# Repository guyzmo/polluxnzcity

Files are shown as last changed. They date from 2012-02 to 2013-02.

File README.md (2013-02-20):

Pollux'NZ City Project
======================

The pollux'NZ City project aims at creating a network of autonomous wireless network
of sensors that uploads the measures on any data silos on Internet.

This repository contains the source code of the first prototype of the project, that
has been deployed  in south of France, with the participation of INRIA Sofia Antipolis,
for a first test run.

Description
===========

The projects is made of two modules:
 * the 'autonomous measuring module', that is made of
   * an arduino with a zigbee radio module ;
   * a battery pack that powers the system ;
   * a solar panel that charges the battery ;
   * an i2c network of sensors.
 * the 'gateway module', that is made of
   * a beaglebone with a zigbee radio module

How it works ?
==============

First, after pluging it in, the user configures the gateway module for his sensor 
network and the interval time between two measures. Then he places the autonomous
sensor module to the best sunlight exposure so the autonomous measuring module can
keep the battery filled up.

The gateway will wait for the given interval time, and waken up the measuring module.
It will then order the measuring module to run the fan, so a free air sample is taken
into the box and run in sequence each sensor to get the measured value. Once all the
sensors have been interrogated, it will tell the measuring module to shut itself down.
Finally, all the measures are given to the enabled plugins that will push the data to
every configured data silo.

Project details
===============

Structure of the project
------------------------

 * Directories

<pre>
PolluxNZCity
    |-- PolluxConfig ............. Contains the configuration plugin (in python)
    |   |-- debian ............... Helper files for package generation
    |   |-- pollux ............... Python module
    |-- PolluxGateway ............ Main program that interfaces with the measuring modules
    |   |-- conf ................. Configuration files that are to be deployed in /etc
    |   |-- extensions ........... Python plugins for uploading data to data silos
    |   |-- include .............. Headers
    |   |-- src .................. Sources
    |   `-- tests ................ Tools that helps testing
    |-- PolluxWakeupduino ........ Main firmware code for the arduino in the measuring module
    |-- PolluxSensorBoard ........ Firmware code for the fan, temperature and noise board
    |-- PolluxSensorDust ......... Firmware code for the dust board
    |-- PolluxSensorSensoric ..... Firmware code for the electrochemical sensoric sensors board
    |-- PolluxSensorTemp ......... Firmware code for the external temperature sensor board
    `-- PolluxContribIpks ........ Helper scripts to build binary packages (for angstrom)
</pre>

 * Branches
   * inria_branch: contains the source code deployed for the INRIA test run
   * i2c_refactoring: non-tested base for a full refactoring of the i2c network

 * Other

In PolluxContribIpks, the package.sh script will run a build and generate the packages
– PolluxConfig and PolluxGateway – that are embedded on the beaglebone. That generator
is now deprecated, the recipes for generating those packages working and being accessible
for the angstrom build system.

Description of the main modules
-------------------------------

* _PolluxConfig_: this module is a web application based on the `bottle.py` module that
  exposes RESTful pathes to the web interface that exposes them using `bootstrap.js`.
  The most important parts are in the `pollux_config` module that contains all the exposed
  routes.
* _PolluxGateway_: this module is the main program that parses the configuration, runs 
  the radio, interrogates every sensor on the distant modules and sends the results
  through every datastore module.
* _PolluxWakeUpduino_: this firmware is the code executed by the embedded arduino that
  is only a gateway between XBee and the i2c network.

The _PolluxGateway_ module has documentation embedded you can generate using `doxygen`,
or by running `make doc` in the directory.

Build and Install
-----------------

* _PolluxConfig_

<pre>
 % cd PolluxConfig
 % python bootstrap.py
 % bin/buildout
 % bin/pollux_config_paster
</pre>

* _PolluxGateway_

first you will need to install the arm-gcc for crosscompilation, or run it directly
on a beaglebone, using native gcc.

<pre>
 % make
 % make doc
 % pollux\_gateway -h
</pre>

for a more verbose version of the software, you can run `make verbose`, that will
create a `pollux\_gateway\_verbose` executable.

Caveats
=======

* The I2C model has been mis-designed. 

We have implemented the i2c stack of the whole project following the way the i2c model
has been implemented in the Arduino and ATTiny wire library suggested ; so we followed
a function calling alike protocol.

But we rapidely found out that this kind of implementation is flawed for our use of 
i2c, as it is not flexible enough and not compatible with most of the i2c modules of
the market. So there's a unfinished implementation of the new i2c handling in the
`i2c_refactoring` branch. That has been not tested at all, and not all the sensors'
firmware has been switched to it.

* The _PolluxGateway_ modules deserves better verbosity

First, instead of compiling two different targets, it should have the common `-v`
switch that makes the executable output more messages. But the verbosity shall also
have levels, so the output is not flooded by the messages.

* The _PolluxGateway_ module shall not configure the MUX values for the xbee cape

We have implemented our first versions of the XBee Cape without the helper EEPROM
that helps the cape autoconfigure the MUX values of the beaglebone. With the new
version of the cape, all the code that configures the MUX settings shall be dropped.
This will finally makes the module work only in userland, and not need to start as
root and drop its privileges once the MUX settings are set.

* The _PolluxGateway_ module and _PolluxWakeUpduino_ firmware shall configure all the zigbee settings

We rely on the manual setting of the XBee modules, to match them up and to configure
their pin ports. That operation is cumbersome, does not work all the time, and needs
to use the X-CTU application under windows.

TODO
====

* finish the refactoring of the i2c stacks
* add more verbosity to the _PolluxGateway_ module
* remove the MUX configuration at _PolluxGateway_ start
* add configuration of the XBee radios in the _PolluxGateway_ module and
  _PolluxWakeUpduino_ firmware.

Copyright
=========

(c)2011-2013 Lucas Fernandez and Bernard Pratz, CKAB, hackable:Devices

 * http://polluxnzcity.org/
 * http://ckab.com/polluxnz-city/
 * http://hackable-devices.org/projects/project/polluxnzcity/

All our original work is licensed under the GNU GPL version 3
and all our schematics are under the Creative Commons v3.0 Attribution Share-Alike.

Here are the Libraries we use in our projects, and their respective copyrights notice

Arduino libraries:
 * Statistics by Rob Tillaart and Gil Ross, in the Public Domain 
 * usiTwiSlave, by Donald R. Blake, Jochen Toppe and Ben Galvin under GPL v2
 * circular buffer based on Akash Nath, in the Public Domain
 * Arduino, by the Arduino team, under the GPL v2

For the python web interface:
 * bottle.py under the MIT License
 * bootstrap.js under the Apache License v2.0.
 * deansi library by David Garcia Garzon, under the AGPLv3

All components symbols in the schematics are from Eagle's libraries, under Creative
Commons v3.0 Share-Alike.

License
=======

This program is free software: you can redistribute it and/or modify
it under the terms of the GNU General Public License as published by
the Free Software Foundation, either version 3 of the License, or
(at your option) any later version.

This program is distributed in the hope that it will be useful,
but WITHOUT ANY WARRANTY; without even the implied warranty of
MERCHANTABILITY or FITNESS FOR A PARTICULAR PURPOSE.  See the
GNU General Public License for more details.

You should have received a copy of the GNU General Public License
along with this program.  If not, see <http://www.gnu.org/licenses/>.

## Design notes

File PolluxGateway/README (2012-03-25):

Pollux Gateway Application
==========================

This program runs the network of sensor devices for the Pollux'nz City project.

Dependencies
============

 * libgcrypt    <http://www.gnu.org/s/libgcrypt/>
 * libjson-glib <http://live.gnome.org/JsonGlib>

Compilation
===========

 % make

You can put in environment a "DEFINE" variable having : 
 * VERBOSE
    to have more output
 * API_ESCAPED_MODE
    to change XBee API Mode from 1 to 2 (still untested)

Execution
=========

 % ./pollux_gateway

License
=======

 * GPLv3        <http://www.gnu.org/licenses/gpl.html>

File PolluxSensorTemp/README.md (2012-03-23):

Board for dust detection for final fing pollux.

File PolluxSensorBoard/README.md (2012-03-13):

Sensor board for final fing pollux.

This sensor board include :
* temperature
* SPL
* Dust PM10

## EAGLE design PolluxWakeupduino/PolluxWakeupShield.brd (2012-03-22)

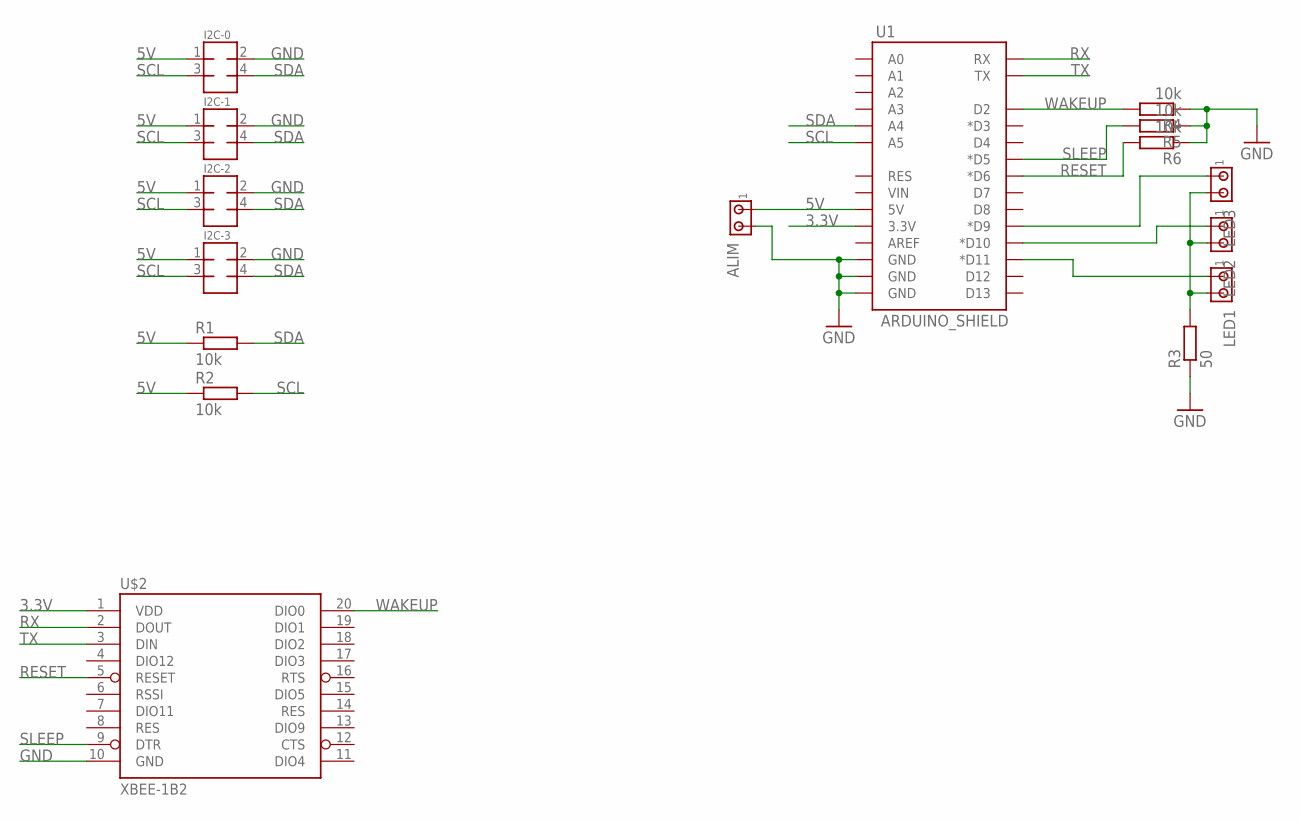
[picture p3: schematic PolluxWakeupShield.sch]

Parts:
ALIM: MTA02-100; 10X02MTA
I2C-0, I2C-1, I2C-2, I2C-3: MMATCH-4-PTH; AMP-215079-4
LED1, LED2, LED3: MTA02-100; 10X02MTA
R1, R2, R4, R5, R6: 10k; 0204/7
R3: 50; 0204/7
U1: ARDUINO_SHIELD; DUEMILANOVE_SHIELD
U$2: XBEE-1B2; XBEE-SILK

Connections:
3.3V: U1.3.3V, U$2.1 (VDD)
5V: ALIM.1, I2C-0.1, I2C-1.1, I2C-2.1, I2C-3.1, R1.1, R2.1, U1.5V
GND: ALIM.2, I2C-0.2, I2C-1.2, I2C-2.2, I2C-3.2, R3.1, R4.1, R5.1, R6.1, U1.GND@0 (GND), U1.GND@1 (GND), U1.GND@2 (GND), U$2.10 (GND)
unnamed: LED1.2, LED2.2, LED3.2, R3.2
unnamed: LED3.1, U1.D9 (*D9)
unnamed: LED2.1, U1.D10 (*D10)
unnamed: LED1.1, U1.D11 (*D11)
RESET: R6.2, U1.D6 (*D6), U$2.5 (RESET)
RX: U1.RX, U$2.2 (DOUT)
SCL: I2C-0.3, I2C-1.3, I2C-2.3, I2C-3.3, R2.2, U1.A5
SDA: I2C-0.4, I2C-1.4, I2C-2.4, I2C-3.4, R1.2, U1.A4
SLEEP: R5.2, U1.D5 (*D5), U$2.9 (DTR)
TX: U1.TX, U$2.3 (DIN)
WAKEUP: R4.2, U1.D2, U$2.20 (DIO0)

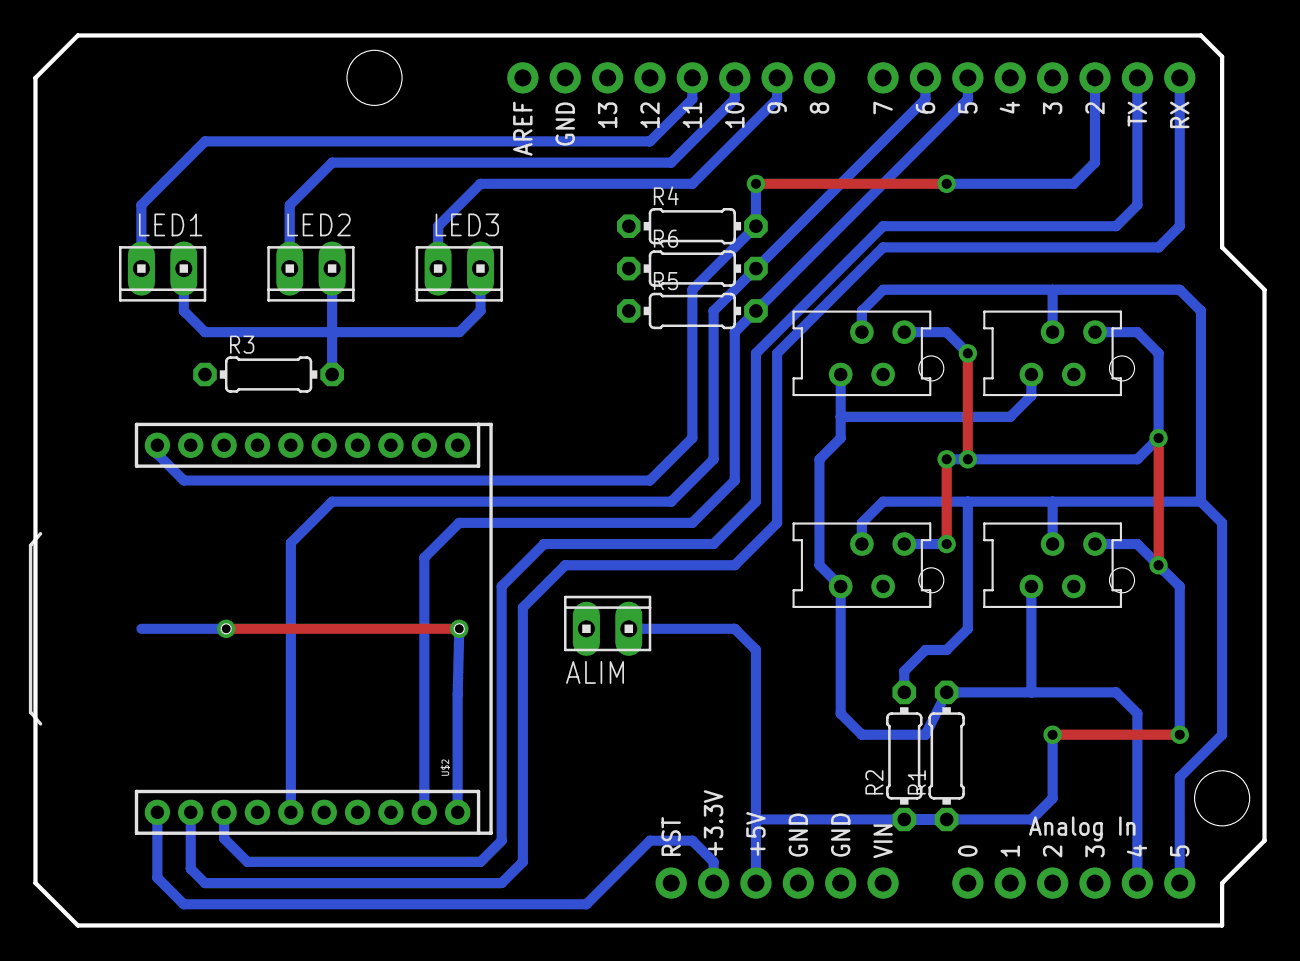
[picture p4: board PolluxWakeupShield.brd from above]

Board: 2 copper layers, 73.7 x 53.3 mm, 16 parts (0 on the bottom side), 14 nets.

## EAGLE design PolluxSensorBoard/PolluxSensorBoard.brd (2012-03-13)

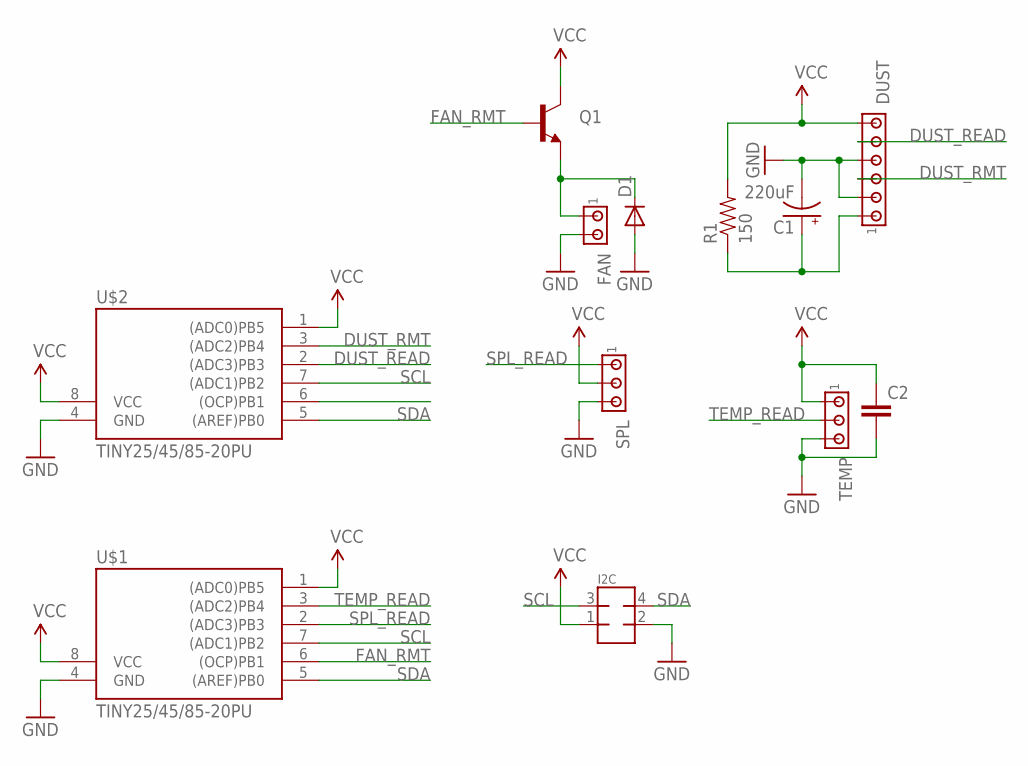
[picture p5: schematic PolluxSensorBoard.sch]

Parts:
C1: 220uF; CPOL-RADIAL-1000UF-25V
C2: CAPPTH1; CAP-PTH-5MM
D1: DIODEPTH; DIODE-1N4001
DUST: MTA06-100; 10X06MTA
FAN: MTA02-100; 10X02MTA
I2C: MMATCH-8-PTH; AMP-215079-8
Q1: TRANSISTOR_NPNTO-92-AMMO; TO-92-AMMO
R1: 150; AXIAL-0.4
SPL: MTA03-100; 10X03MTA
TEMP: MTA03-100; 10X03MTA
U$1, U$2: TINY25/45/85-20PU; DIL08

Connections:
DUST_READ: DUST.2 (5), U$2.2 ((ADC3)PB3)
DUST_RMT: DUST.4 (3), U$2.3 ((ADC2)PB4)
FAN_RMT: Q1.2 (B), U$1.6 ((OCP)PB1)
GND: C1.2 (-), C2.2, D1.A, DUST.3 (4), DUST.5 (2), FAN.2, I2C.2, SPL.3, TEMP.3, U$1.4 (GND), U$2.4 (GND)
unnamed: D1.C, FAN.1, Q1.1 (E)
unnamed: C1.1 (+), DUST.6 (1), R1.P$1 (1)
SCL: I2C.3, U$1.7 ((ADC1)PB2), U$2.7 ((ADC1)PB2)
SDA: I2C.4, U$1.5 ((AREF)PB0), U$2.5 ((AREF)PB0)
SPL_READ: SPL.1, U$1.2 ((ADC3)PB3)
TEMP_READ: TEMP.2, U$1.3 ((ADC2)PB4)
VCC: C2.1, DUST.1 (6), I2C.1, Q1.3 (C), R1.P$2 (2), SPL.2, TEMP.1, U$1.1 ((ADC0)PB5), U$1.8 (VCC), U$2.1 ((ADC0)PB5), U$2.8 (VCC)

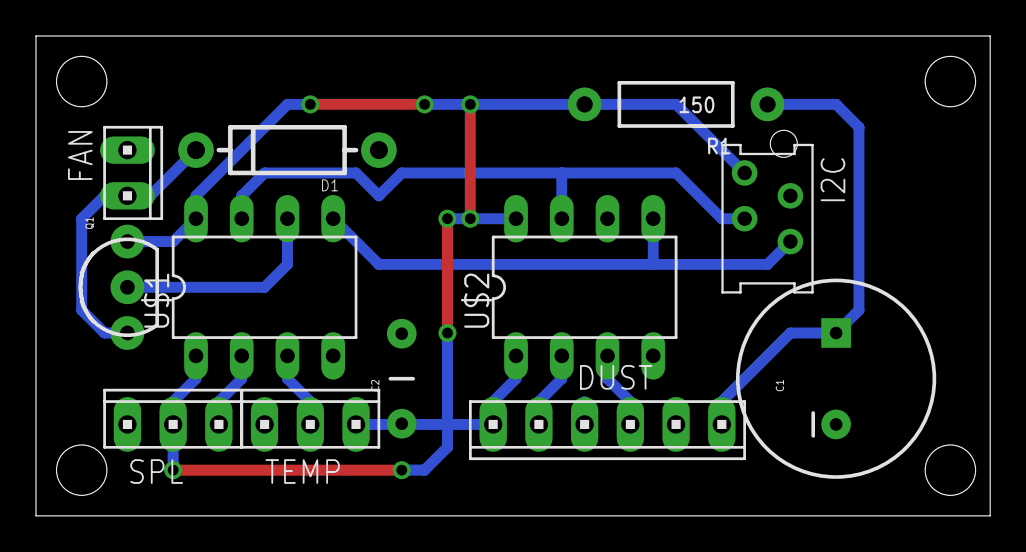
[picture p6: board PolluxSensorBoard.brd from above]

Board: 2 copper layers, 53.0 x 26.7 mm, 12 parts (0 on the bottom side), 11 nets.

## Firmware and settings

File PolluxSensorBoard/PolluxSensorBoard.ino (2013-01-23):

/**
 * Pollux'NZ City Project
 * Copyright (c) 2012 CKAB, hackable:Devices
 * Copyright (c) 2012 Bernard Pratz <guyzmo{at}hackable-devices{dot}org>
 * Copyright (c) 2012 Lucas Fernandez <kasey{at}hackable-devices{dot}org>
 *
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
                  +-\/-+
        (RESET)  1|    |8  VCC (2.7-5.5V)
            SPL  2|    |7  I2C   SCK -> Uno A5
      Temp Read  3|    |6  Fan Remote
            GND  4|    |5  I2C   SDA -> Uno A4
                  +----+ 
*/
#define I2C_SLAVE_ADDR 0x27 // I2C slave address

//#define DESC "Temperature sensor"
#include <TinyWire.h>

#include "Statistic/Statistic.h"      // Arduino Statistic lib

#define TEMP_READ      2    // Temp  read on pin 3 (ADC2)
#define SPL_READ       3    // SPL   read on pin 2 (ADC3)
#define FAN_RMT        PB1  // Fan output on pin 6 (PB1)

#define DELAY_ADC       10  // time before re-read ADC 10 us

TinyWire Wire;


////////////////////////////////////////////////////////////////////////////////

// sensor  dbmeter
// 680  == 345 == 90dB
// 672  == 330 == 85dB
// 620  == 415 == 80dB
// 450? == 397 == 75dB
// 420? == 390 == 70dB
// 270  == 331 == 66dB
inline byte convert_to_dB(float val) {
    // 10.0 == 50dB
    if (val<10.0)        return 50; // <50dB
    // 15.0 == 55dB
    else if (val<15.0)   return 55; // <55dB
    // 30.0 == 60dB
    else if (val<30.0)   return 60; // <60dB
    // 70.0 == 65dB
    else if (val<70.0)   return 65; // <65dB
    // 140.0 == 70dB
    else if (val<140.0)  return 70; // <70dB
    // 230.0 == 75dB
    else if (val<230.0)  return 75; // <75dB
    // 250.0 == 80dB
    else if (val<255.0)  return 80; // <80dB
    // 255.0 == 85dB == 90 dB
    else if (val<255.0)  return 85; // <85dB
    else //if (val>=255.0)
        return 90; // >85dB
}

byte get_spl(Statistic* stat) {   
    byte result;

    for(uint8_t i=0;i<50;i++) {            // make 50 temperature sample
        stat->add(analogRead(SPL_READ));  // read and store temperature sensor output
        delayMicroseconds(DELAY_ADC);      // wait 10 us to stabilise ADC
    }

    result = (byte)convert_to_dB(stat->average());
    stat->clear();

    return result;
}

float get_temp(Statistic* stat) {
    float result;
    for(uint8_t i=0;i<50;i++) {            // make 50 temperature sample
        stat->add(analogRead(TEMP_READ));        // read and store temperature sensor output
        delayMicroseconds(DELAY_ADC);      // wait 10 us to stabilise ADC
    }

    result = ((stat->average()*0.0049)-0.5125)*100 ; // convert the result into a humain readable output

    if(result < 0) result = 0;             // avoid eratic datas
    stat->clear();                         // clear statistics to avoid leack and data stacking

    return result;
}

void run_fan() {
    digitalWrite(PB1,HIGH);
    for (int i=0;i<10;++i)
        delay(10000);
    digitalWrite(PB1,LOW);
}

////////////////////////////////////////////////////////////////////////////////
uint8_t i=0;

void sensor_meas() {
    Statistic stat;
    float res_f = 0;
    uint8_t res_b = 0;

    uint8_t* float_ptr;

    switch (i++) {
        case 0:
            run_fan();
            Wire.set_type(I2C_INT);
            Wire.write((uint8_t)0xFF); // msb
            Wire.write((uint8_t)0xFF); // lsb
            break;

        case 1:
            res_b = get_spl(&stat);
            Wire.set_type(I2C_INT);
            Wire.write((uint8_t)res_b); // msb
            Wire.write((uint8_t)0x0);   // lsb
            break;
            
        case 2:
            res_f = get_temp(&stat);
            float_ptr = (uint8_t*)&res_f;
            Wire.set_type(I2C_FLT);
            Wire.write(*(float_ptr)); // send 1st byte of float
            Wire.write(*(float_ptr+1)); // send 2nd byte of float
            Wire.write(*(float_ptr+2)); // send 3rd byte of float
            Wire.write(*(float_ptr+3)); // send 4th byte of float
            break;
    }
    if (i == 3) i = 0;
}

void setup() {
    pinMode(PB1,OUTPUT);
    pinMode(TEMP_READ,INPUT);
    pinMode(SPL_READ,INPUT);

    Wire.begin(I2C_SLAVE_ADDR); // slave address
    Wire.set_request_callback(&sensor_meas);
}

void loop() {
 /* nop */
}

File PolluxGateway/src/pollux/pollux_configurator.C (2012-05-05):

/*
 * Pollux'NZ City source code
 *
 * (c) 2012 CKAB / hackable:Devices
 * (c) 2012 Bernard Pratz <guyzmo{at}hackable-devices{dot}org>
 * (c) 2012 Lucas Fernandez <kasey{at}hackable-devices{dot}org>
 *
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
 */

#include <pollux/pollux_sensors.h>
#include <pollux/pollux_configurator.h>

using namespace pollux;

inline bool json_object_has_key(struct json_object* obj, const std::string& key) {
    json_object_object_foreach(obj, k,v) {
        if (std::string(k) == key) 
            return true; 
    }
    return false;
}

Sensor::Sensor(std::string name, std::string unit, uint8_t addr, uint8_t reg, uint8_t length, std::string type) : 
                                                                            name(name), unit(unit), address(addr), reg(reg), length(length), type(type) {
    this->ignored = false;
}
uint8_t Sensor::get_length() {
    return this->length;
}

std::string Sensor::get_type() {
    return this->type;
}

std::string Sensor::get_name() {
    return this->name;
}
std::string Sensor::get_unit() {
    return this->unit;
}
uint8_t Sensor::get_address() {
    return this->address;
}
uint8_t Sensor::get_reg() {
    return this->reg;
}
bool Sensor::is_ignored() {
    return this->ignored;
}

Action::Action(std::string name, uint8_t addr, uint8_t reg) : Sensor(name,"",addr,reg,0,"") {
    ignored = true;
}
bool Action::is_ignored() {
    return ignored;
}

Pollux_configurator::Pollux_configurator(std::string& conf, std::string& ext) : path_conf(conf), path_ext(ext) {
}
const std::string& Pollux_configurator::get_config_option(std::string key) const {
    return configuration_map[key];
}
const std::string& Pollux_configurator::get_datastore_value(std::string& ds, std::string& value) const {
    return datastores_map[ds][value];
}

const std::string& Pollux_configurator::get_path_to_extensions() const {
    return this->path_ext;
}

void Pollux_configurator::load_configuration() {
    std::ostringstream fname;

    fname << path_conf << "/config.json";
    struct json_object *json_data;

    json_data = json_object_from_file((char*)fname.str().c_str());
    if (is_error(json_data)) {
        throw Pollux_config_exception("Invalid JSON file. Please check your configuration file.");
    }
    if (!json_object_has_key(json_data,"configuration")) {
        throw Pollux_config_exception("Missing 'configuration' token in configuration file.");
    }

    struct json_object* config = json_object_object_get(json_data, "configuration");

    if (!json_object_has_key(config,"tty_port")) {
        throw Pollux_config_exception("Missing 'tty_port' token in configuration section.");
    }
    if (!json_object_has_key(config,"wud_sleep_time")) {
        throw Pollux_config_exception("Missing 'wud_sleep_time' token in configuration section.");
    }

    json_object_object_foreach(config,key,value) {
        configuration_map[key] = json_object_get_string(json_object_object_get(config,key));
#ifdef VERBOSE
        std::cout<<"config."<<key<<": "<<json_object_get_string(json_object_object_get(config,key))<<std::endl;
#endif //VERBOSE
    }

    free(json_data);
}
void Pollux_configurator::load_geoloc() {
    std::ostringstream fname;

    fname << path_conf << "/config.json";
    struct json_object *json_data;

    json_data = json_object_from_file((char*)fname.str().c_str());
    if (is_error(json_data)) {
        throw Pollux_config_exception("Invalid JSON file. Please check your configuration file.");
    }
    if (!json_object_has_key(json_data,"geolocalisation")) {
        throw Pollux_config_exception("Missing 'geolocalisation' token in configuration file.");
    }

    struct json_object* config = json_object_object_get(json_data, "geolocalisation");

    if (!json_object_has_key(config,"latitude")) {
        throw Pollux_config_exception("Missing 'latitude' token in geolocalisation section.");
    }
    if (!json_object_has_key(config,"longitude")) {
        throw Pollux_config_exception("Missing 'longitude' token in geolocalisation section.");
    }

    json_object_object_foreach(config,key,value) {
        geoloc_map[key] = json_object_get_string(json_object_object_get(config,key));
#ifdef VERBOSE
        std::cout<<"geoloc."<<key<<": "<<json_object_get_string(json_object_object_get(config,key))<<std::endl;
#endif //VERBOSE
    }

    free(json_data);
}
void Pollux_configurator::load_datastores() {
    struct json_object *json_data;
    std::ostringstream fname;

    fname << path_conf << "/config.json";

    json_data = json_object_from_file((char*)fname.str().c_str());
    if (is_error(json_data)) {
        throw Pollux_config_exception("Invalid JSON file. Please check your configuration file.");
    }

    if (!json_object_has_key(json_data,"datastores")) {
        throw Pollux_config_exception("Missing 'datastores' token in configuration file.");
    }

    struct json_object* datastores = json_object_object_get(json_data, "datastores");

    json_object_object_foreach(datastores,name,datastore) {
        json_object_object_foreach(datastore,key,value) {
#ifdef VERBOSE
            printf("datastore(%s).%s: '%s'\n", name, key, json_object_get_string(json_object_object_get(datastore,key)));
#endif //VERBOSE
            datastores_map[name][key] = json_object_get_string(value);
        }
    }

    free(json_data);
    return;
}
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

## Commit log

2011-12-02 [FIX #424] code for temperature sensor
2011-12-03 [ENH #423] Added code for NO2 sensor. Need more validation.
2011-12-03 [ENH #422] added dust sensor code
2012-02-14 removing sensor test files, already sent to the branch sensor-test
2012-02-14 [ENH #625] added gateway and sensor initial codes
2012-02-22 add Sound and temperature codes
2012-02-22 initial pop schematic and board for dust sensor
    [I2CDustSensor.brd, I2CDustSensor.sch]
2012-02-22 rm fucking files thanks to eagle
    [I2CDustSensor.brd, I2CDustSensor.sch]
2012-02-22 add sensors schematics and brd
    [PolluxSensorDust.brd, PolluxSensorDust.sch, PolluxSensorSound.brd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]
2012-02-22 [ENH #425] added noise sensor code
2012-02-22 add dust sensor schematics and board
    [PolluxSensorDust.brd, PolluxSensorDust.sch, PolluxSensorSound.brd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]
2012-02-22 add Temp sensor board and schematics
    [PolluxSensorSound.brd, PolluxSensorSound.sch, PolluxSensorTemp.brd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]
2012-02-22 add SPL sensor board and schematics
    [PolluxSensorSound.brd, PolluxSensorSound.sch]
2012-02-23 improve sensor board
    [PolluxSensorDust.brd, PolluxSensorDust.sch, PolluxSensorSound.brd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]
2012-03-01 [ENH #625] reverted to XBee original library
    [PolluxWakeupduino.ino]
2012-03-02 added pollux gateway base code and init uart script
2012-03-03 updated comments in init uart2
2012-03-03 [ENH #625] minor fix
    [PolluxWakeupduino.ino]
2012-03-04 [ENH #625] added beaglebone led features and enabled them
2012-03-04 [ENH #625] housekeeping, disabled leds on ^C
2012-03-04 [ENH #625] enabling/disabling UART2 from source code
2012-03-05 added placeholder for i2c code
2012-03-05 improve sound sensor
2012-03-07 Add new board schematic and brd
    [PolluxSensorBoard.brd, PolluxSensorBoard.sch]
2012-03-07 Add code for new sensor board
2012-03-08 working i2c version of temperature
2012-03-11 add Wakeupshield with I2C and XBee connector. Recently added wakeup from xbee and sleep mode from arduino
    [PolluxWakeupShield.brd, PolluxWakeupShield.sch]
2012-03-13 [ENH #625] updated led report stuff
2012-03-13 removed PB4 led debug
2012-03-13 added new shield LED support
2012-03-13 removed all not directly useful code -- saved in sensor-proto branch
    [PolluxSensorSound.brd, PolluxSensorSound.sch]
2012-03-13 [ENH #623] added tinywireslave's code to pollux sensorboard
2012-03-13 [ENH #623] removed old pollux temperature code
    [PolluxSensorTemp.brd, PolluxSensorTemp.sch]
2012-03-13 [ENH #623] moved shield schematics to wakeupduino folder
    [PolluxWakeupShield.brd, PolluxWakeupShield.sch]
2012-03-13 dd last schematics with xbee improvement
    [PolluxWakeupShield.brd, PolluxWakeupShield.sch]
2012-03-23 [ENH #625] updated Pollux WUD code as a i2c<->zigbee bridge ; working code
2012-03-23 [ENH #623] updated makefile for embedded sensors
2012-03-23 [ENH #623] updated last sensor code for SensorBoard ; working code
2012-03-23 [ENH #623] added dust sensor code ; not working (gives 0.0 value...)
    [PolluxSensorDust.ino]
2012-03-23 [ENH #623] updated i2c communication so it halts when alone ; corrected hardcoded addresses in code
2012-03-23 [ENH #623][ENH #625] added i2c<->zigbee poll loop for multiple sensor checking
2012-03-23 [ENH #626][ENH #625][ENH #624] added mockup of observer pattern for multiple sensors support ; added static sensors definition ; added JSON data build
2012-03-25 added updated sensors test file
2012-03-28 Add sensoric AVR code
2012-03-28 enhance backend sensor + advenced
2012-03-28 [ENH #624][ENH #626] updated code with json configuration, new observer... STILL BUGGY
    [beagle_serial.C]
2012-03-31 updated code with sleep time support from config ; with working sensors reading and pushing
2012-04-13 updated main code so order of sensors is respected
2012-04-14 added namespaces ; fixed makefile
    [beagle_serial.C, pollux_configurator.C]
2012-04-14 added dynamic library support for datastores addon feature ; failure on execution
    [pollux_configurator.C]
2012-04-17 fixed extension loading module
    [pollux_configurator.C]
2012-04-17 added base support for calibration
2012-04-17 add sensor sensoric code
2012-04-17 updated pollux config in master
    [buildout.cfg, data.csv]
2012-04-17 added uninstall support in polluxconfig
    [data.csv]
2012-04-20 added datastore activation support ; improved sensors support
2012-04-20 fixed sensors code to support generation from sensors_list.json
2012-04-21 added comments ; refactored to extract prober/calibrator from configuration ; added pollux_calibrator code ; extracted signal handling from pollux_xbee
2012-04-21 updated sensors_list
2012-04-21 solved compilation issues ; updated support for unprivileged execution
    [pollux_calibrator.C, pollux_configurator.C]
2012-04-25 updated default values to sensor dust
2012-04-27 updated sensors' list source
2012-05-04 added support for '-s' option to avoid the fork
    [pollux_calibrator.C]
2012-05-04 added support for remote activation/deactivation of the Arduino using AT REMOTE ; improved output
2012-05-05 added verbosity flags to compilation ; corrected warnings' causes
    [pollux_calibrator.C, pollux_configurator.C]
2012-05-09 fixed bug: bringing WUD off when timeout
    [PolluxWakeupduino.ino]
2012-05-22 commented out disabled buttons
2012-05-31 added support for status of services in case of no logs
2012-08-24 [ENH] updated buildout/setup
    [buildout.cfg]
2012-09-03 add new sensor temp
2012-09-06 Revert "updated default values to sensor dust"
    This reverts commit 4c4130744d3128e336709e3b6a73def85ad82c9f.
    [PolluxSensorDust.ino]
2012-09-06 [FIX] reverted 4c413074,2713b195,1ad7e67 on PolluxSensorDust to get back to original TinyWire model
    [PolluxSensorDust.ino, TinyWire.cpp, TinyWire.h]
2012-09-06 [FIX] refactored pollux sensor temp to original tinywire model
    [PolluxSensorTemp.ino, TinyWire.cpp, TinyWire.h]
2012-09-06 [ENH] added new temperature calculation function (not tested)
2013-01-23 [FIX] corrected path to attiny files in Pollux Temperature Sensor
2013-01-23 [FIX] improved temperature correction in SensorBoard
    [PolluxSensorBoard.ino]

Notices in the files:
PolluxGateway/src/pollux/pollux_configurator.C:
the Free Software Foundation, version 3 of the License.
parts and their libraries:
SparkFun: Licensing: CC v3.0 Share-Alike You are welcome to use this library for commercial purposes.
